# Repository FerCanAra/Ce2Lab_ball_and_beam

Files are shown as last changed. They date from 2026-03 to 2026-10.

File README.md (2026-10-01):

# Unlocking the Development and Experiences ofControl Education Labs (Ce2Lab) 





The shortage of physical lab models in university control engineering laboratories is a widely recognized problem at theinternational level. In response to this challenge, this paper presents CE2Labs (Unlocking the Development and Experiences ofControl Education Labs), a teaching innovation project funded by theIFAC Activity Fundand developed by an internationalteam of educators and laboratory engineers from universities in Spain, Sweden, France, Germany, and the United Kingdom.The project proposes the design and construction of low-cost, open-source physical lab models at different levels of complexity,ranging from 3D-printed mechanical devices to Arduino-based and custom electronics solutions, as well as the developmentof an open-access web platform where educators worldwide can access the materials and share experiences.



Visit the project [OFFICIAL website](https://arm.ual.es/ce2lab2/#) for more information. This work was carried out within the [Automation, Robotics and Mechatronics Group](https://arm.ual.es/arm-group/) (ARM TEP 197) at the University of Almería (Spain).

<a href="https://arm.ual.es/arm-group/"> 
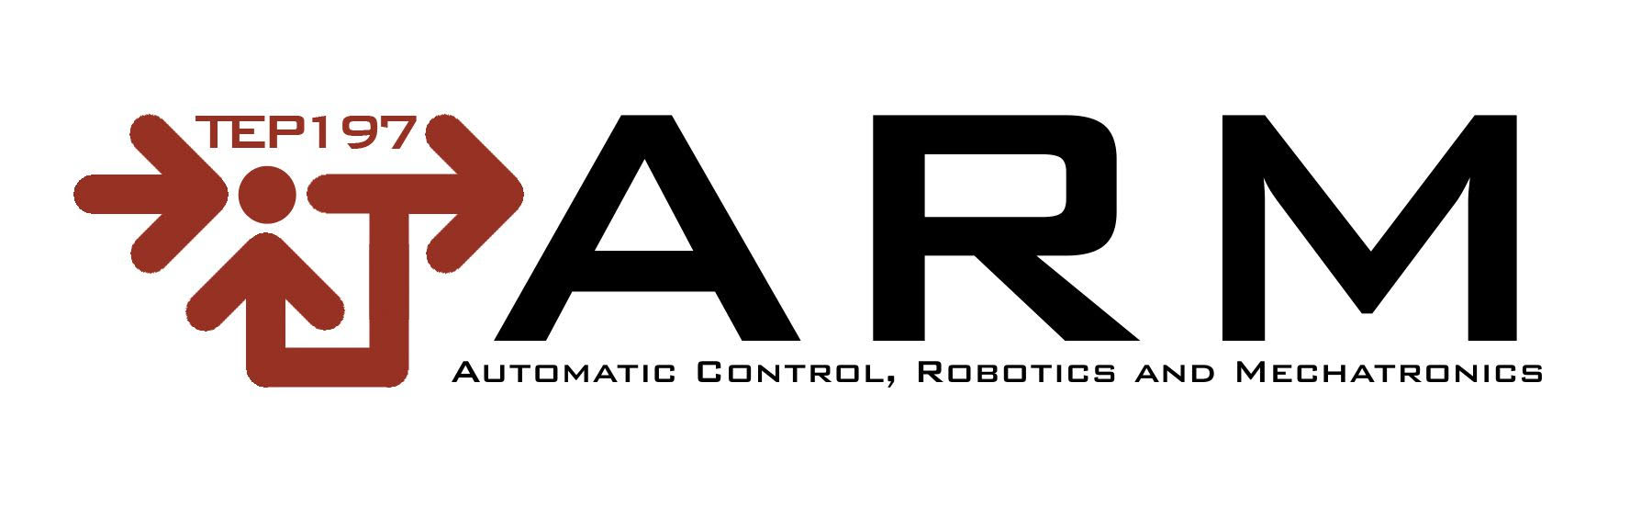
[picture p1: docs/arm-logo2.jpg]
ARM Group Logo
   
</a>
<a href="https://www.linkedin.com/company/automatic-robotics-and-mechatronics-research-group/"> 
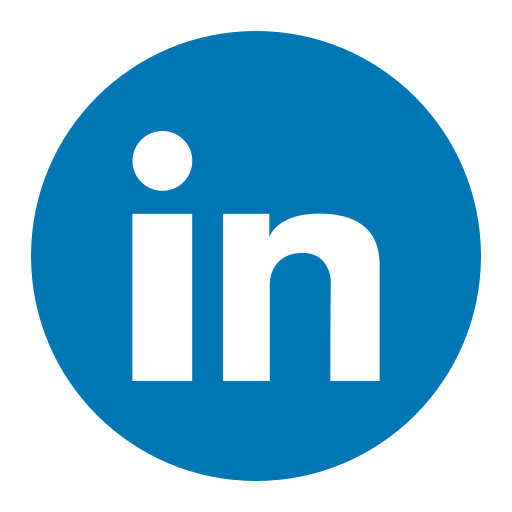
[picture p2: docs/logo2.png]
LinkedIn Logo
   
</a>

## 📑 Citation

**_Project article_**

```
@article{sanchez2026democratizando,
  title={Democratizando los laboratorios de control: la iniciativa CE2Labs},
  author={S{\'a}nchez, Jos{\'e} Luis Guzm{\'a}n and Gil, Juan Diego and Ca{\~n}adas-Ar{\'a}nega, Fernando and Pataro, Igor ML and Rodr{\'\i}guez-Miranda, Enrique and Gonz{\'a}lez-Her{\'a}ndez, Jos{\'e} and Mu{\~n}oz-Rodr{\'\i}guez, Manuel and Berenguel, Manuel},
  journal={Jornadas de Autom{\'a}tica},
  number={47},
  year={2026}
}
```

**_Ball and beam article_**

```
@article{aranega2026plataforma,
  title={Plataforma Ball and Beam de bajo coste como apoyo a la ense{\~n}anza de conceptos introductorios de modelado y control autom{\'a}tico},
  author={Ca{\~n}adas-Aranega,Fernando  and Pataro, Igor M.L. and Rodr{\'\i}guez, Enrique and Gil, Juan Diego and Luis Guzm{\'a}n, Jos{\'e}},
  journal={Jornadas de Autom{\'a}tica},
  number={47},
  year={2026}
}
```
**_Software citation_**
  
```
@software{c2d_project,
  author={Ca{\~n}adas-Aranega,Fernando  and Pataro, Igor M.L. and Rodr{\'\i}guez, Enrique and González, José and Muñoz, Manuel and Gil, Juan Diego and Luis Guzm{\'a}n, Jos{\'e}},
  title   = {Ce2Lab Repository Project},
  version = {0.0.1},
  year    = {2026},
  doi     = {https://doi.org/10.5281/zenodo.23079949},
  url     = {https://github.com/FerCanAra/Ce2Lab_ball_and_beam/tree/main}
}
```

## Ce2Lab - Watt Governor

This repository contains the STL files required to build a simple **Watt Governor demonstrator** for educational use. The objective of the model is to provide a **visual and intuitive demonstration** of how a centrifugal governor works. By rotating the central shaft manually, the user can observe how the rotating masses move outward as the rotational speed increases, causing the central collar to move vertically.

Go to [official site](Watt%20Governor/) for full details on the complete project.

## Ce2Lab - Ball and Beam

The Ball and Beam system is a classic experiment widely used in control engineering to study PID control techniques. The objective of the system is to maintain a ball at a desired position along a beam by adjusting the beam's angle. This is achieved by continuously measuring the ball position and applying a PID control action to a servo motor that tilts the beam.

Go to [official site](Ball%20and%20Beam/) for full details on the complete project.

## License

<details>
<summary>This project is licensed under the **BSD 3-Clause License**.</summary>

Copyright (c) 2026, Fernando Cañadas Aránega, Igor Mendes Lima Pataro, Enrique Rodríguez Miranda, José González Hernández, José Luis Guzmán Sánchez and Juan Diego Gil Vergel.

All rights reserved.

Redistribution and use in source and binary forms, with or without modification,
are permitted provided that the following conditions are met:

1. Redistributions of source code must retain the above copyright notice,
this list of conditions and the following disclaimer.

2. Redistributions in binary form must reproduce the above copyright notice,
this list of conditions and the following disclaimer in the documentation
and/or other materials provided with the distribution.

3. Neither the name of the copyright holders nor the names of its contributors
may be used to endorse or promote products derived from this software without
specific prior written permission.

THIS SOFTWARE IS PROVIDED BY THE COPYRIGHT HOLDERS AND CONTRIBUTORS "AS IS"
AND ANY EXPRESS OR IMPLIED WARRANTIES ARE DISCLAIMED.

For the complete license text see the `LICENSE` file in this repository.
</details>

## Contributor

[Fernando Cañadas Aránega](https://linktr.ee/fercanara), 
Igor Mendes Lima Pataro,
Enrique Rodríguez Miranda, 
José González Hernández,
[Jose Luis Guzman Sánchez](https://w3.ual.es/personal/joguzman/) and
[Juan Diego Gil Vergel](https://w3.ual.es/personal/jdgil/).

## References

Code template: [AntonAshraf](https://github.com/AntonAshraf/Ball-Beam-PID-Control/tree/main)

stl template: [OlegKor25](https://www.thingiverse.com/thing:6387659)

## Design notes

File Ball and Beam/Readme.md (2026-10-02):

# Ce2Lab - Ball and Beam

The Ball and Beam system is a classic experiment widely used in control engineering to study PID control techniques. The objective of the system is to maintain a ball at a desired position along a beam by adjusting the beam's angle. This is achieved by continuously measuring the ball position and applying a PID control action to a servo motor that tilts the beam.

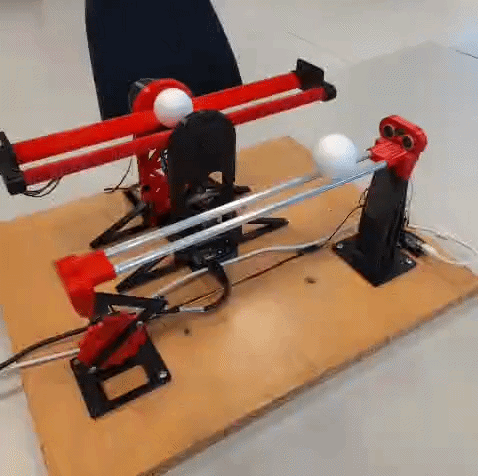
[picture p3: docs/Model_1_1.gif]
 

In this project, a different ATmega328P-based implementation of the Ball and Beam system is developed, using an ultrasonic and laser sensors to measure the ball's position and a servo motor to control the beam angle. A PID (Proportional–Integral–Derivative) controller is implemented to automatically adjust the beam inclination, keeping the ball close to the desired target position.

> **Note:** Process tested with Windows 11 with PlatformIO (VSC) on 8th April 2026.

## Ball and Beam GUI

A web interface is also available, allowing you to run simulations in HTML and connect to the actual model for direct interaction. Follow this [official site](Ball%20and%20Beam%20GUI/) to learn more.

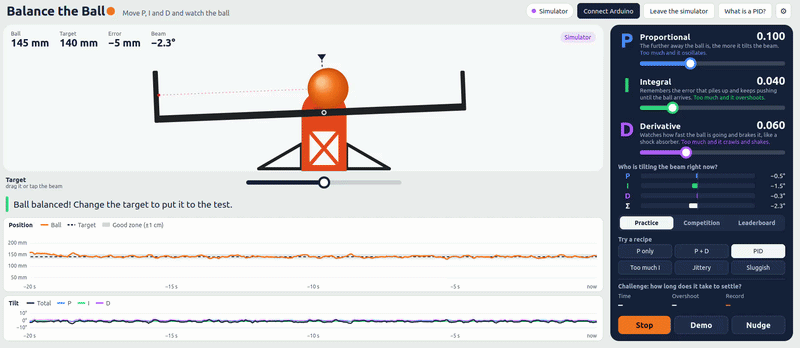
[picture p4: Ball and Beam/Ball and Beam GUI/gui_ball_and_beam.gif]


<details>
<summary>Model 1</summary>

A “Ball and Beam” with its support in the center:

image-removebg-preview


<details>
<summary>1. Materials and cost</summary>

### 3D printing of parts

A Prusa MK4 (0.4 mm nozzle) printer was used. The total printing time is: 7h 39min + 10h 28min + 14h 54min + 1h 34min = 34h 35 min. Parameters:
- Layer height: 0.15 mm
- First layer height: 0.2 mm
- Infill: 5 %
- Raft: No
- Supports: Yes
- Ironing: 15 mm/s

Printing material:

- PLA 1.75 mm
- Extruder temperature: 215 °C
- Bed temperature: 60 °C
- PLA consumption: 78.73 g + 102.63 g + 146.65 g + 13.52 g = 341.53 g (5%)

### Additional material

Mechanical components:
- 12 × M4 Allen screws
- 7 x Jumper Wire 
- 1 x Hot glue
- 1 x Ping-pong ball

Electronic components:
- 1 × ATMega328P (Microcontroller socket board): 10 €
- 1 × MG996r motor: 6 €
- 1 × 341.53 g of PLA roll: 6.50 € (19€/kg)
- 1 × VL53L0X: 1.0 €

### Cost per prototype

Total cost: 23.50 €

</details>

<details>
<summary>2. Assembly</summary>

If you're reusing the code, try connecting everything as shown in the image below:



</details>
</details>
<details>
<summary>Model 2</summary>

A “ball-and-beam” structure supported at one end (with the same model at the other end)




<details>
<summary>1. Materials and cost</summary>

### 3D printing of parts

A Prusa MK4 (0.4 mm nozzle) printer was used. The total printing time is: 12 h 27 min
- Layer height: 0.15 mm
- First layer height: 0.2 mm
- Infill: 5 %
- Raft: No
- Supports: Yes
- Ironing: 15 mm/s

Printing material

- PLA 1.75 mm
- Extruder temperature: 215 °C
- Bed temperature: 60 °C
- PLA consumption: 112.5 g (5%)

### Additional material

Mechanical components:
- 3 × M4 1 cm Allen screws
- 2 x M2 8 cm Allen screws
- 2 x M2 washers
- 1 x 7 mm hollow aluminum rod: 2 €

Electronic components:
- 1 × ATMega328P (Microcontroller SMD board): 3.3 €
- 1 × MG996r motor: 6 €
- 1 × 112.2 g of PLA roll: 2.20 € (19€/kg)
- 1 × HC-SR04: 2.5 €

### Cost per prototype

Total: 16 €

</details>

<details>
<summary>2. Assembly</summary>

If you're reusing the code, try connecting everything as shown in the image below:



</details>
</details>

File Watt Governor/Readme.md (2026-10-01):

## Ce2Lab - Watt Governor

This repository contains the STL files required to build a simple **Watt Governor demonstrator** for educational use.

The purpose of the model is to provide a **visual and intuitive demonstration** of how a centrifugal governor works. By rotating the central shaft manually, the user can observe how the rotating masses move outward as the rotational speed increases, causing the central collar to move vertically.

The model is intended to help explain the balance between centrifugal effects and gravity, as well as the influence of mechanical parameters such as the **mass of the balls** and the **length of the arms**.

<details>
<summary>1. Materials and cost</summary>

### STL files to print

To assemble one complete model, print:

- 2 × `Ball.stl`
- 2 × `Bal_2.stl`
- 1 × `Base.stl`
- 1 × `Slider.stl`
- 1 × `Knob.stl`
- 1 × `Top.stl`
- 1 × `Collar.stl`
- 1 × `Dial.stl`
- 2 × `Arm_couple.stl`
- 2 × `Arm.stl`

## Additional hardware

The following non-printed components are required:

- 6 × M3×20 screws
- 1 x 8 mm aluminium rod
- Hot glue
- 1 × 623Z bearing
- 1 × 608Z bearing
- Hot glue

## Tool
- Hot glue gun
- Steel saw
- Screwdriver

### Cost per prototype

Total cost: 10.50 €

</details>

<details>
<summary>2. Notes</summary>

The demonstrator is designed primarily as a **visual and interpretative teaching aid** rather than as an instrumented control experiment. No motor or rotational-speed sensor is required for the basic activity.

</details>

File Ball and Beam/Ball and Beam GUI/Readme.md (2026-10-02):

# Balance the Ball — getting started

Ball and beam rig with an Arduino UNO, a Hitec HS-422 servo and a VL53L0X ToF sensor.
The PID runs on the Arduino; the PC is only an interface for changing parameters and watching the response.

## Contents

| File | What it is |
|---|---|
| `BallBeam_Expo/BallBeam_Expo.ino` | Arduino firmware: sensor reading, filtering, PID, servo and serial protocol |
| `balance_the_ball.html` | Interface for the public; a single file you open in Chrome or Edge |

If you close the browser the rig keeps controlling, because the loop runs on the Arduino.
That is also why it starts up in PID mode even with no PC attached.

---

## 1. Wiring

| Item | Pin |
|---|---|
| Servo, signal | D11 |
| Servo, power | 5–6 V from a **separate supply** (2 A or more); ground **common** with the Arduino |
| VL53L0X VIN / GND | 5 V / GND (the module has its own regulator) |
| VL53L0X SDA / SCL | A4 / A5 |

During a long public event it matters that the servo is not powered from USB.
When the servo pulls hard, USB can sag below what the UNO needs and the Arduino resets.
The interface counts those resets in the operator panel. If the count climbs, this is why.

## Beam geometry

The beam has been shortened from the original build. The values the program uses are:

| Quantity | Value |
|---|---|
| Ball against the near end stop | 42 mm |
| Ball in the middle of the beam | 140 mm |
| Ball against the far end stop | 238 mm |
| Target, minimum and maximum | 70 and 210 mm |
| Target at start-up | 140 mm |

The 42 mm minimum follows from the other two: if the middle reads 140 and the far stop reads 238, the near stop falls at 140 − (238 − 140) = 42 mm.

If you change the beam length again, only `POS_MIN`, `POS_MAX`, `SP_MIN`, `SP_MAX` and `SP_DEFAULT` at the top of the sketch need editing. The interface reads these from the Arduino as soon as it connects (the `#CFG` message) and adapts the drawing, the target slider and the charts on its own, so the HTML needs no changes.

## 2. Loading the firmware

1. In the Arduino IDE open *Tools → Manage Libraries* and search for **VL53L0X**. Install the one by **Pololu**, not the Adafruit one. The `Servo` library already ships with the IDE.
2. Open `BallBeam_GUI/BallBeam_GUI.ino`. The folder has to have the same name as the file.
3. Select the *Arduino Uno* board and the right port, and upload.
4. If you open the Serial Monitor at 115200 baud you should see `#READY`, `#CFG,...` and lines starting with `$`.
5. **Close the Serial Monitor** before using the interface: only one program at a time can hold the port.

The parameters you may need to touch are grouped at the top of the file: servo pin, position range, default target, angle limits and observer settings.
Everything that depends on your particular build (level angle, direction, limit and gains) is adjusted from the interface and stored in EEPROM.

## 3. Opening the interface

1. Open `balance_the_ball.html` with **Chrome or Edge**. Firefox and Safari do not support Web Serial.
2. Press **Connect Arduino** and pick the port. Next time you open the page it connects on its own.
3. It needs no internet, so you can copy the file to the event laptop and open it directly.

With no rig attached, the **Simulator** button gives you the same controller as the firmware running against your identified model. It is useful for rehearsing the explanation, or for keeping people busy while someone else is using the rig.

## 4. One-off setup (⚙ Operator settings)

1. **Level.** Tick *Manual mode* with the manual tilt at 0°. Adjust *Servo angle that levels the beam* until the ball barely moves. The starting value is 85°.
2. **Sensor.** Move the ball along the beam by hand. The *Sensor reading* should follow it smoothly between about 42 and 238 mm. With the ball in the middle of the beam it should read about 140 mm; if it does not, check the end stops or where the sensor sits.
3. **Direction.** Set a manual tilt of +5°. The ball must move **away from the sensor**. If it comes closer, press *Flip direction*. This build needs −1, which is the default.
4. **Limit.** 15° is a good compromise. Larger values make the rig quicker but also harsher.
5. Untick manual mode and press **Save to the Arduino**. From then on it starts up with these values.

If the ball consistently runs off to one end with the PID recipe, step 3 is wrong. With the direction inverted, the more you raise P the sooner the ball escapes.

---

## 5. How it works inside

### The plant
Tilting the beam accelerates the ball:

`ẍ = K · (θ + tilt error)`, with K ≈ 83.5 mm/s² per degree.

That is the value from the `fmincon` identification: K_b ≈ 4.79 m/s²/rad. The plant is a **double integrator**. Tilt does not set the position of the ball, nor even its speed, but its acceleration.

### Why D is essential
With P alone the beam acts like a spring: it pushes the ball towards the target, but nothing brakes it, so the ball oscillates for ever.
D opposes the speed and plays the part of a damper.
I removes the error that is left when the beam is not perfectly level or friction is in play.

### Units of the gains
- **Kp** [°/mm]: at 0.10, a 10 mm error tilts the beam by 1°.
- **Ki** [°/(mm·s)]: at 0.04, a 10 mm error held for 1 s adds 0.4°.
- **Kd** [°·s/mm]: at 0.06, a ball travelling at 100 mm/s produces 6° of braking.

Starting values: **Kp = 0.10, Ki = 0.04, Kd = 0.06**. These are the ones that already worked on this rig: beam length does not change the relation between tilt and acceleration, so the gains still hold. With the short beam the errors are smaller, the beam tilts less, and the ball settles slightly sooner, in about 3–5 s, with a final error of 5 mm or less.

What does change is the margin to the end stops: from the highest target (210 mm) there are only 28 mm left before the end of the beam. With the more aggressive recipes the ball will touch the stop, bounce, and the controller will recover it. This is harmless and turns out to be rather instructive to watch.

### Filtering: alpha-beta observer with a model
Differentiating a measurement carrying 20–30 mm of noise makes the servo shake.
The firmware first applies a median of 3, which kills the spikes, and then an **observer** that predicts where the ball should be using the model and corrects that prediction with the measurement:
- `α = 0.35` corrects position and `β = 0.05` corrects speed.
- `γ = 0.001` estimates the real tilt error of the beam, bounded to ±5°. Without this term the P+D recipe settled about 20 mm short of the target.
- If the ball jumps more than 60 mm, for instance because someone picks it up, the observer resets.
- Near the end stops it stops using the model and freezes the tilt estimate. Otherwise it "believes" a ball resting against a wall is still moving.

In simulation the servo shake drops from about 1.1–2.6° with conventional filters to about 0.6°.

### PID details
- **Derivative on the measurement**, not on the error, so changing the target produces no sudden kick.
- **Anti-windup**: the integral stops accumulating once the beam is already at its limit in that direction, and it is bounded to ±8° anyway.
- The servo is driven with `writeMicroseconds`, giving about 0.1° of resolution instead of 1°.
- The sensor is polled without blocking. If it fails, the beam goes level and the Arduino retries once a second.

---

## 6. The interface for the public

- **P, I and D sliders**, each with a plain-language line and a warning about what happens if you overdo it.
- **"Who is tilting the beam right now?"**: shows in real time how many degrees each term contributes. This is the single most useful panel for explaining a PID.
- **Recipes**, worth trying in this order:
  - **P only**: the ball oscillates.
  - **P + D**: it settles, but about 18 mm short of the target.
  - **PID**: it reaches the target.
  - **Too much I**: it overshoots.
  - **Jittery**: it shakes.
  - **Sluggish**: it never gets there.
- **Coach**: suggests which slider to move based on what the ball is doing.
- **Challenge** (*Practice* tab): move the target by 3 cm or more and it times how long the ball takes to stay within ±1 cm for 1.5 s, and keeps the record. If someone touches the gains halfway through, that time does not count.
- **Target**: set by dragging on the drawing of the beam or with the slider below it.
- **Keyboard**: *Space* stops or starts, *Esc* closes panels. During a competition, *Space* stops control and voids the go.
- **Automatic demo** after 90 s with nobody touching anything: it goes back to the PID recipe and cycles through targets. It can be turned off in ⚙.

### Competition mode

On the **Competition** tab, the *Start* button deals out a random target and random gains, starts the clock and waits. You have to move P, I and D until the ball sits still on the target (±1 cm) for **3 seconds in a row**. The time runs from *Start* to the moment the ball entered the good zone and never left it again.

On success a dialog shows the time, the position obtained and a box for a name. The **Leaderboard** tab shows the standings.

Details worth knowing for the event:

- The starting gains come from four archetypes (no brakes, extremely jittery, too much memory, everything maxed out), with random values inside each. They are chosen so that **none of them settles on its own**: this was checked over 320 simulated goes, with the beam level and with a tilt error of ±1.5°. Nobody wins without touching anything.
- The target always lands 7 cm or more from wherever the ball is, so there is ground to cover.
- During a go the target slider, the recipes and the demo button are locked. Otherwise pressing "PID" would be enough to win.
- The coach stops giving hints during a go and only reports the time. If you would rather it kept helping, for instance with small children, turn it on in ⚙ → *Keep the coach hints during the competition*.
- If someone stops control, switches to manual mode, or the Arduino resets, the go is voided. The limit per go is 2 minutes.
- The leaderboard is stored in the browser on the laptop (`localStorage`), so it survives reloading the page and closing the browser. Clear it from ⚙ → *Clear the leaderboard*. It is a good idea to empty it right before opening to the public.
- If the browser has local storage blocked, the interface says so on the leaderboard tab and the standings last only while the page is open.

### Tips for the event
- Walk people through this sequence: *P only → raise the D → raise the I*. That is how each letter earns its place. Once someone has the three letters, move them to the competition tab: that is where it hooks.
- Leave the good values saved on the Arduino so a reset does not leave the rig out of tune.
- Go full screen (F11) and stop the laptop from sleeping.
- Bring a spare ball. Ping-pong balls get dented, and a dented ball rolls differently.

---

## 7. Serial protocol (115200 baud, one command per line)

Useful if you want to drive the firmware from MATLAB or Python.

**PC → Arduino**

| Command | Meaning |
|---|---|
| `P0.1` `I0.04` `D0.06` | Gains |
| `S180` | Target in mm (between 70 and 210) |
| `M0` / `M1` / `M2` | Stopped (beam level) / PID / manual |
| `A5` | Angle in manual mode (°) |
| `L15` | Tilt limit (°) |
| `N85` | Servo angle that levels the beam |
| `X-1` | Servo direction |
| `R` | Clear the integral |
| `W` | Store in EEPROM |
| `?` | Resend the configuration |

**Arduino → PC**

- `$t,pos,sp,u,p,i,d,mode,raw,ok,tilt` at about 30 Hz.
- `#CFG,...` with the current configuration.
- `#SAVED` once stored in EEPROM.
- `#ERR,SENSOR` if the sensor fails.
- `#READY` on start-up.

## 8. Common problems

| Symptom | Likely cause |
|---|---|
| "Port busy" | The IDE Serial Monitor is open |
| The reset counter climbs | The servo is powered from USB |
| The ball always escapes to one end | Direction inverted (step 3) |
| With P at zero the ball rolls on its own | Level angle not adjusted (step 1) |
| The reading jumps a lot | Dirty sensor, direct sunlight, or the ball outside its measuring range |
| No connect button appears | The browser is not Chrome or Edge |

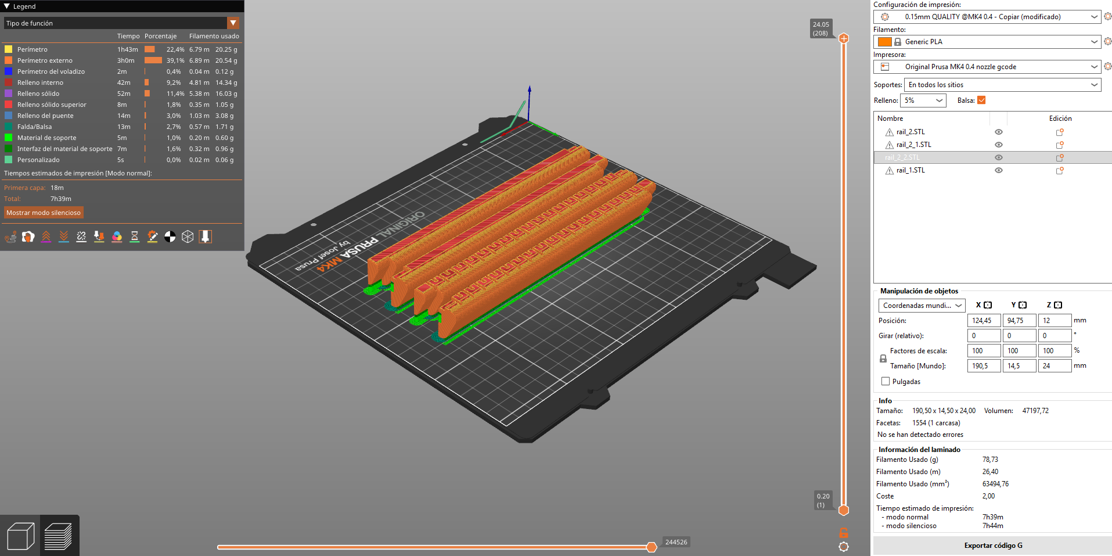
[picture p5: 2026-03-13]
Ball and Beam/Model 1/images/info_1.png

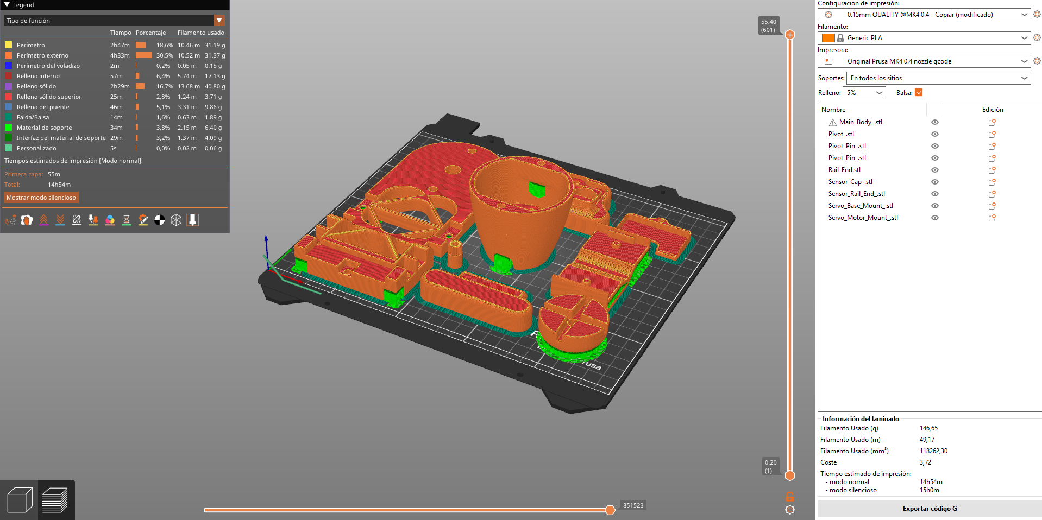
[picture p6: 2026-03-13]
Ball and Beam/Model 1/images/info_4.png

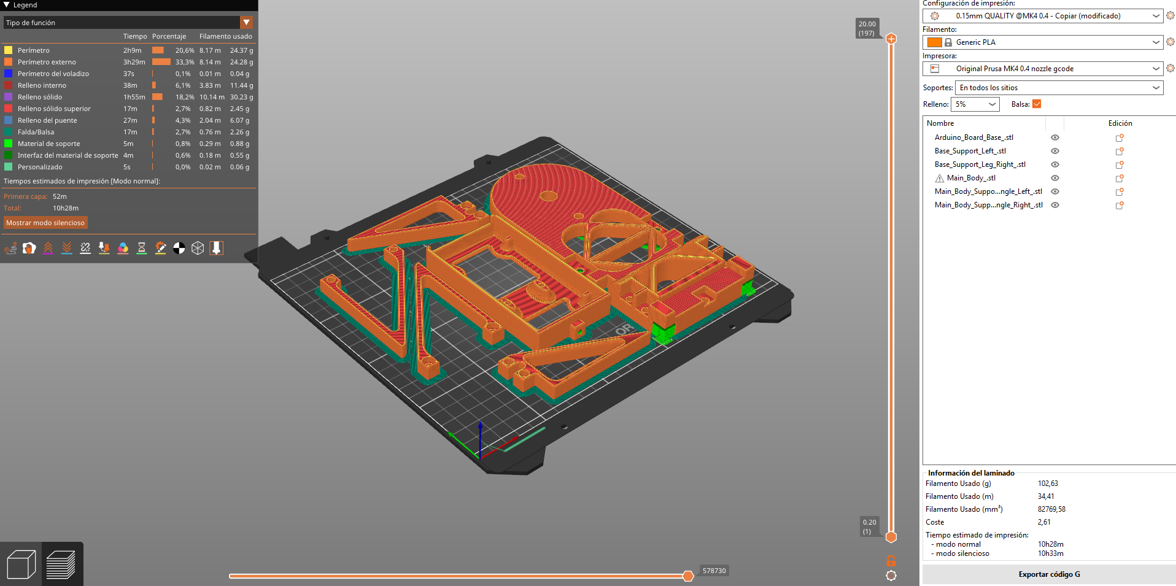
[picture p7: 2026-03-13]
Ball and Beam/Model 1/images/info_2.png

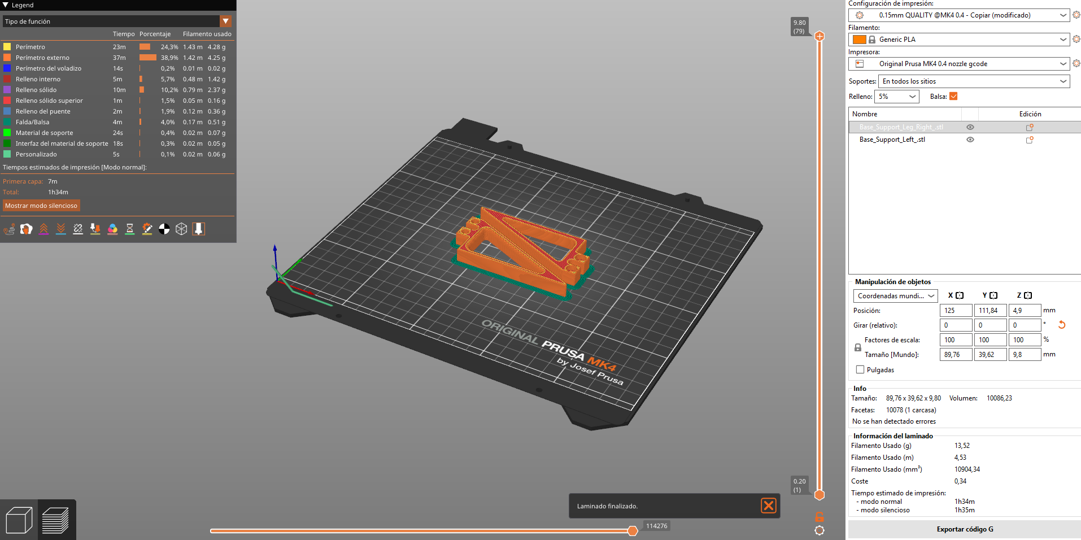
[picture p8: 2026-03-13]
Ball and Beam/Model 1/images/info_5.png

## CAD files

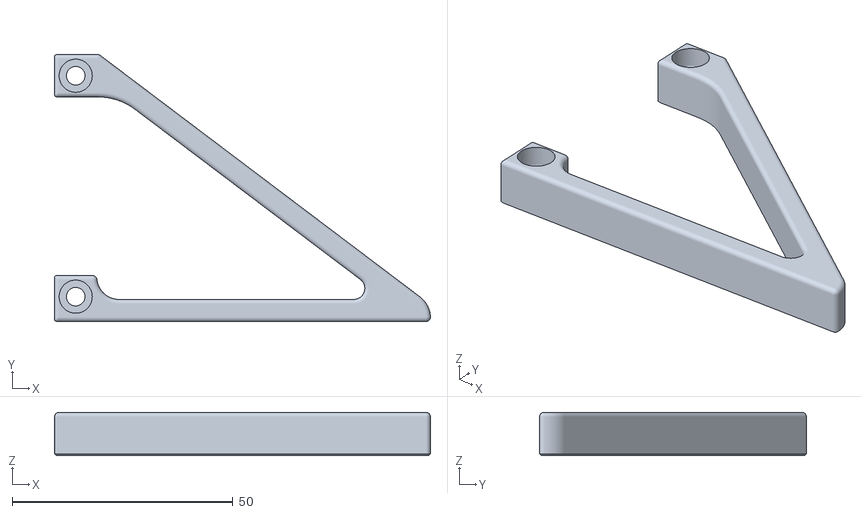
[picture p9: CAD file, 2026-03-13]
Ball and Beam/Model 1/stl/Main_Body_Support_Triangle_Left_.stl
85.1 x 60.4 x 9.80

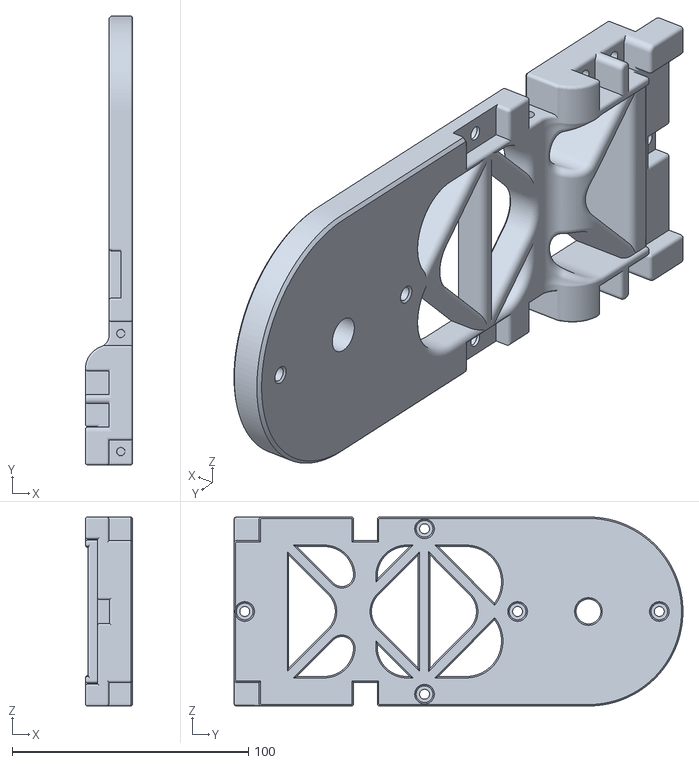
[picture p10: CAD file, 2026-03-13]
Ball and Beam/Model 1/stl/Main_Body_.stl
20.0 x 190.0 x 80.0

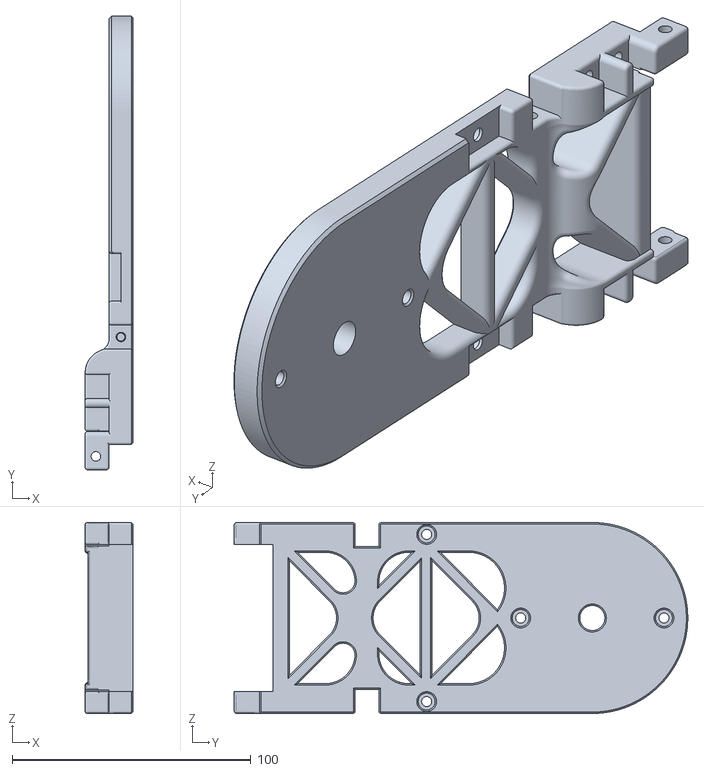
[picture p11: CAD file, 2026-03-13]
Ball and Beam/Model 1/stl/Main_Body_2.STL
20.0 x 190.0 x 80.0

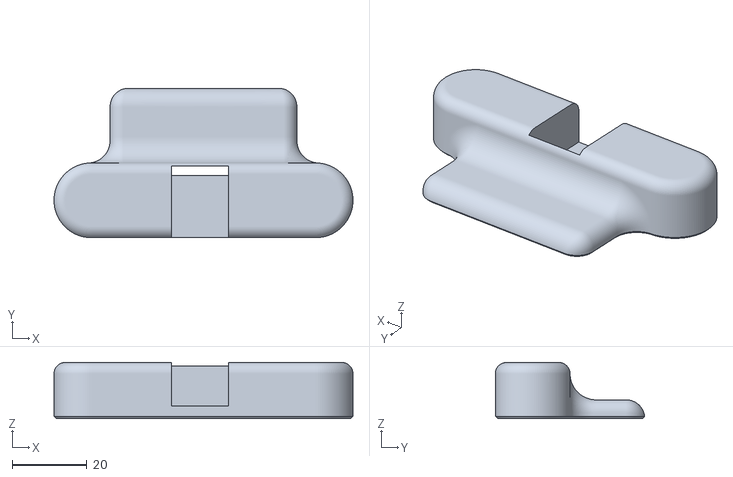
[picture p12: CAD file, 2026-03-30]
Ball and Beam/Model 1/stl/Rail_End_sensor.STL
80.0 x 40.0 x 15.0

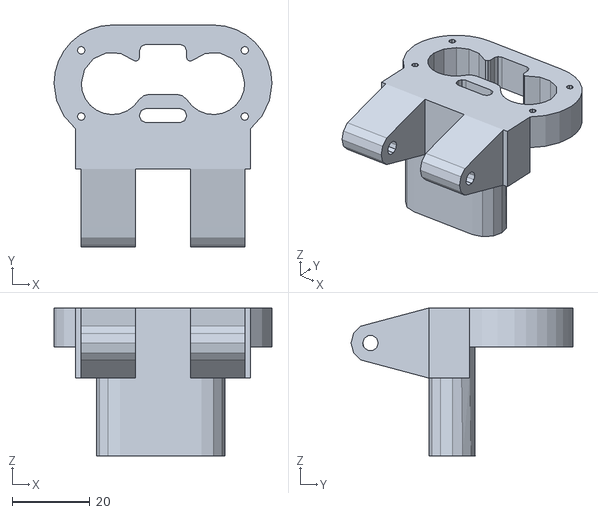
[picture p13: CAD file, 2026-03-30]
Ball and Beam/Model 2/stl/Ultrasonic_sensor_.stl
56.0 x 57.0 x 38.0

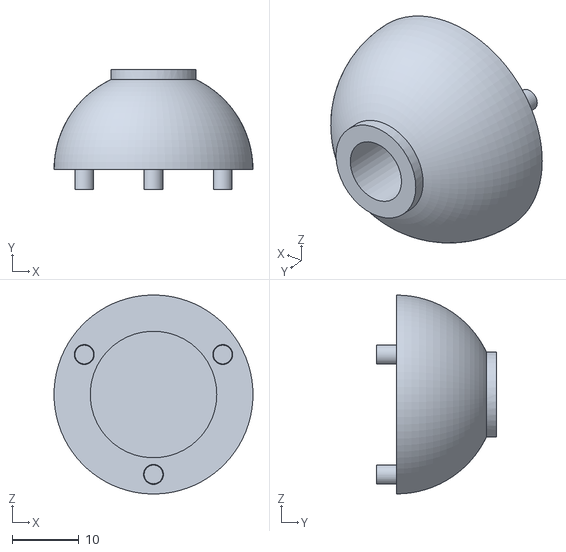
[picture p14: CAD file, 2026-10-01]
Watt Governor/stl/Ball_2.STL
29.9 x 18.0 x 29.8

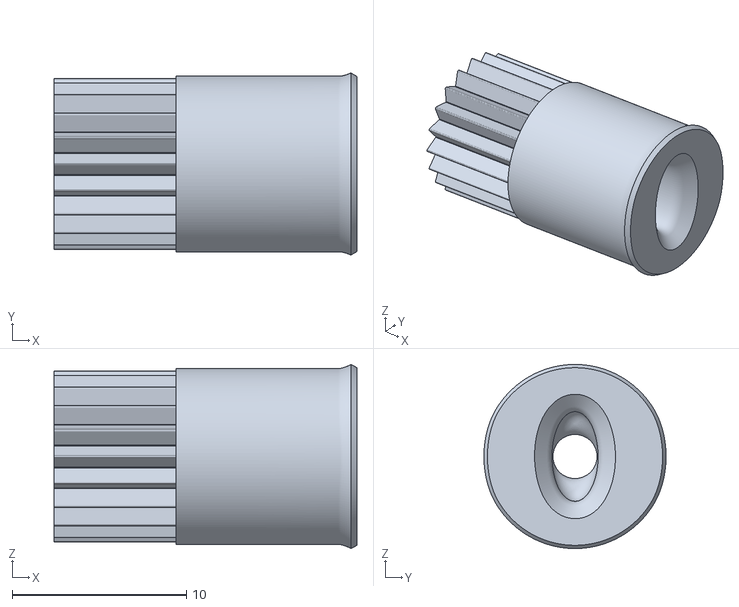
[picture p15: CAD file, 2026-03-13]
Ball and Beam/Model 1/stl/Pivot_Pin_.stl
17.4 x 10.5 x 10.6

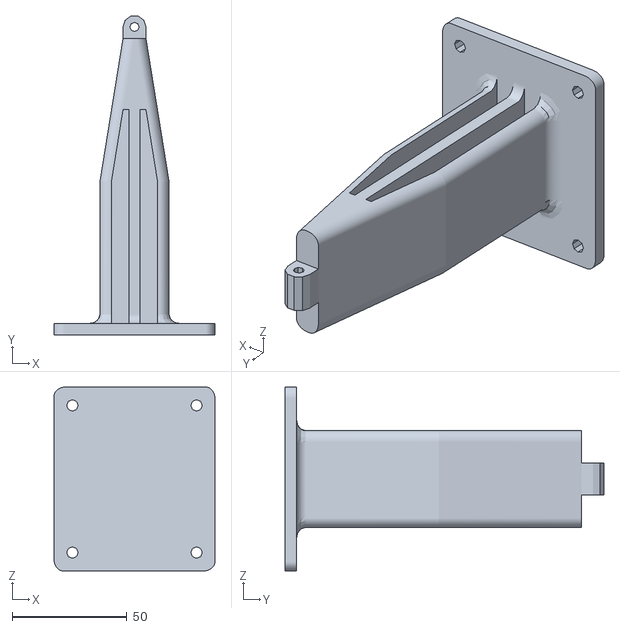
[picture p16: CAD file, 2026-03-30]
Ball and Beam/Model 2/stl/base.stl
70.0 x 138.8 x 80.0

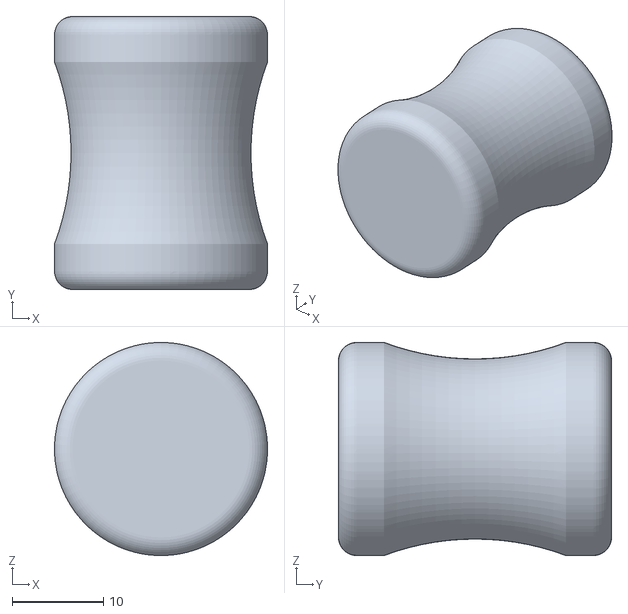
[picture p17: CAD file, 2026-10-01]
Watt Governor/stl/Knob.STL
23.4 x 30.0 x 23.4

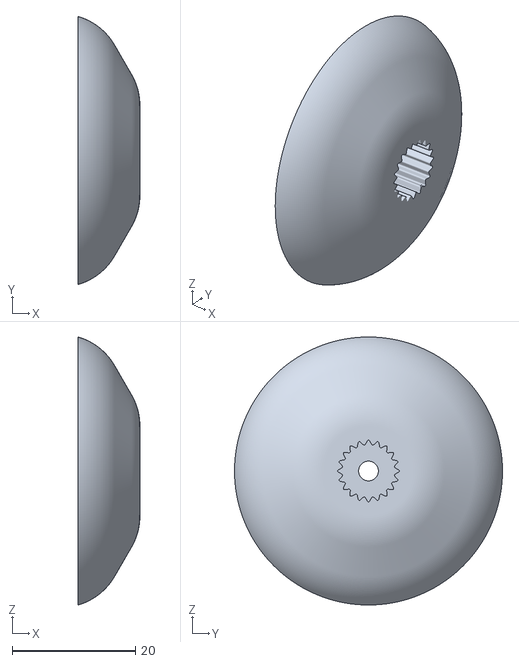
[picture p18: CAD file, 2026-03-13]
Ball and Beam/Model 1/stl/Servo_Motor_Mount_2.STL
10.0 x 43.5 x 43.5

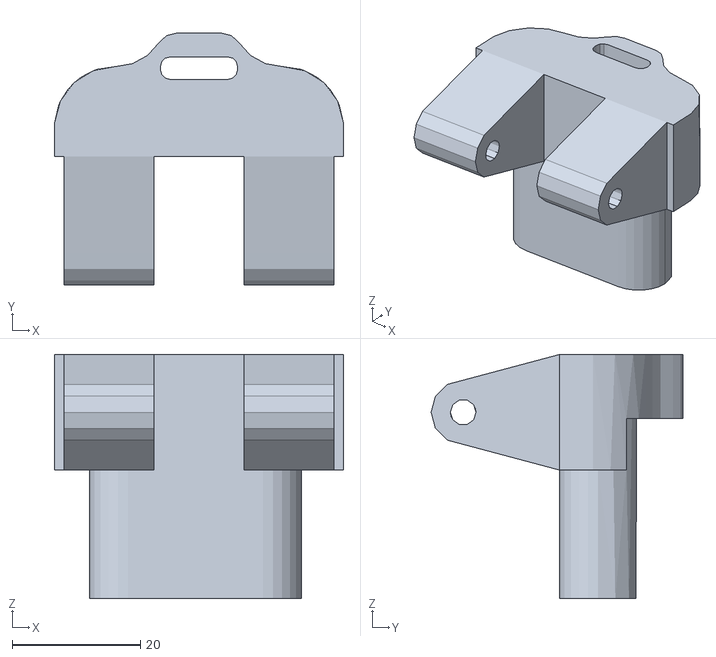
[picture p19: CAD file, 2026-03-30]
Ball and Beam/Model 2/stl/rail_end_.stl
45.0 x 39.2 x 38.0

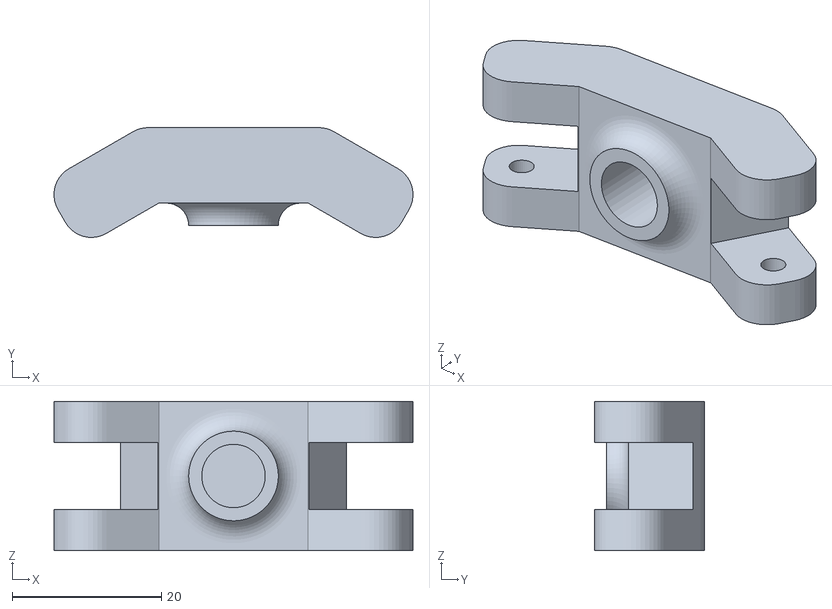
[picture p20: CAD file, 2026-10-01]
Watt Governor/stl/Top.STL
48.0 x 14.7 x 20.0

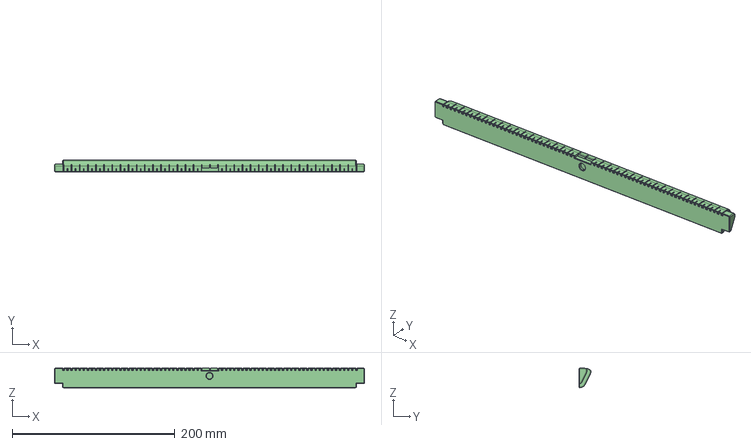
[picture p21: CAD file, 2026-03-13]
Ball and Beam/Model 1/stl/Rail_wRuler_.step
381.0 x 14.5 x 24.0 mm

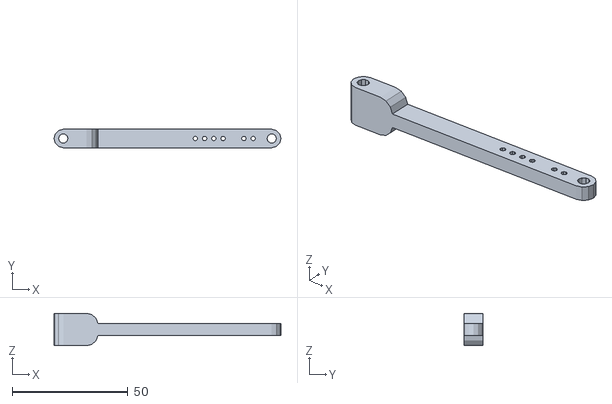
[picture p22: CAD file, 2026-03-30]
Ball and Beam/Model 2/stl/biel.stl
98.0 x 8.00 x 14.0

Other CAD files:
Ball and Beam/Model 1/stl/Main_Body_Support_Triangle_Right_.stl
Watt Governor/stl/Arm_63mm.STL
Ball and Beam/Model 2/stl/Servobase.stl
Watt Governor/stl/Base.STL
Ball and Beam/Model 1/stl/Arduino_Board_Base_.stl
Ball and Beam/Model 1/stl/Base_Support_Left_.stl
Ball and Beam/Model 1/stl/Base_Support_Leg_Right_.stl
Ball and Beam/Model 1/stl/Breadboard_Bracket_Print_x2.stl
Ball and Beam/Model 1/stl/Pivot.STL
Ball and Beam/Model 1/stl/Pivot_.stl
Ball and Beam/Model 1/stl/Pivot_Pin_2.STL
Ball and Beam/Model 1/stl/Rail_.step
Ball and Beam/Model 1/stl/Rail_.stl
Ball and Beam/Model 1/stl/Rail_End.stl
Ball and Beam/Model 1/stl/Rail_with_Ruler.stl
Ball and Beam/Model 1/stl/Servo_Base_Mount_.STL
Ball and Beam/Model 1/stl/Servo_Motor_Mount_.stl
Watt Governor/stl/Arm.STL
Watt Governor/stl/Arm_53mm_.STL
Watt Governor/stl/Arm_couple.STL
Watt Governor/stl/Ball.STL
Watt Governor/stl/Collar.STL
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

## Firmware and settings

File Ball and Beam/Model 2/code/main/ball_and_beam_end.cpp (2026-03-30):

/* -------------------------------------------------------------------------------------------------------------
Project: Ball and Beam PID Control System

Authors:
Fernando Cañadas Aránega, email: fernando.ca@ual.es
Enrique Rodriguez Miranda, email: erm969@ual.es
José Luis Guzmán Sánchez, email: joguzman@ual.es

License: BSD 3-Clause License
Copyright (c) 2026, Fernando Cañadas Aránega, Enrique Rodriguez Miranda and José Luis Guzmán Sánchez.
All rights reserved.

See the LICENSE file or the README.md for full license information.
// NOTE: For the beam to be horizontal,
// the servo motor angle should be about 95 degrees.
-------------------------------------------------------------------------------------------------------------
*/ 
#include <Arduino.h>
#include <Servo.h>
#include <PID_v1.h>

// Function prototypes (we will define them later)
void resetServo();      // Moves the servo to a safe starting position
float readPosition();   // Reads the distance from the ultrasonic sensor

// Pins used by the ultrasonic sensor
const int trigPin = 9;
const int echoPin = 10;

// Pin used by the servo motor
const int servoPin = 11;

// PID parameters
// These numbers define how strongly the system corrects errors
float Sp = 10;   // Setpoint (desired distance in cm)
float Kp = 0.25;   // Proportional correction (reacts to the error)
float Ki = 0.0;    // Integral correction (reacts to accumulated error)
float Kd = 0.2;    // Derivative correction (smooths the movement)

// Variables used by the PID controller
double Setpoint, Input, Output, ServoOutput;

// Create the PID controller object
PID myPID(&Input, &Output, &Setpoint, Kp, Ki, Kd, DIRECT);

// Create the servo object
Servo myServo;

// Filter parameters
// This filter helps smooth the distance measurement
float alpha = 0.4;              // Number between 0 and 1
float filteredDistance = 0.0;   // Memory of the filtered value

void setup() {

  // Start communication with the computer
  Serial.begin(9600);

  // Attach the servo motor to its pin
  myServo.attach(servoPin);

  // Move the servo to a safe starting position
  resetServo();

  // Configure ultrasonic sensor pins
  pinMode(trigPin, OUTPUT);
  pinMode(echoPin, INPUT);  

  // Take the first distance measurement to initialize the filter
  filteredDistance = readPosition();
  Input = filteredDistance;

  // Turn on the PID controller
  myPID.SetMode(AUTOMATIC);

  // Limit how much the servo can move
  myPID.SetOutputLimits(-60,80);
}

void loop(){

  // Wait 50 milliseconds
  // This means the system updates 20 times per second
  delay(50);

  // Desired distance (target)
  // The system will try to keep the ball at 8 cm
  Setpoint = Sp;

  // Read the real distance from the sensor
  float rawDistance = readPosition();

  // LOW-PASS FILTER
  // This makes the measurement smoother and less noisy
  filteredDistance = alpha * rawDistance + (1 - alpha) * filteredDistance;

  // The filtered value is used as the system input
  Input = filteredDistance;

  // The PID controller calculates how much to move the servo
  myPID.Compute();
  
  // Convert PID output into a servo angle
  ServoOutput = 95 + Output;

  // Move the servo to that angle
  myServo.write(ServoOutput);

  // Print information to the serial monitor
  Serial.print("Raw: ");          // Raw sensor distance
  Serial.print(rawDistance);

  Serial.print("  Filtered: ");   // Filtered distance
  Serial.print(filteredDistance);

  Serial.print("  Angle: ");      // Servo angle
  Serial.println(ServoOutput);
}

// This function centers the servo
void resetServo() {
  myServo.write(90);   // 90 degrees is the middle position
  delay(500);          // Wait half a second
}

// This function measures distance using the ultrasonic sensor
float readPosition() {

  // Send a short pulse so the sensor emits a sound wave
  digitalWrite(trigPin, LOW);
  delayMicroseconds(2);

  digitalWrite(trigPin, HIGH);
  delayMicroseconds(10);
  digitalWrite(trigPin, LOW);

  // Wait until the echo returns
  long duration = pulseIn(echoPin, HIGH);

  // Convert echo time into distance (in cm)
  float distance = duration * 0.034 / 2;

  // If the value is strange or too large,
  // we use a fixed value to avoid errors
  if (distance > 30 || distance <= 0) {
    distance = 40;
  }

  return distance;
}

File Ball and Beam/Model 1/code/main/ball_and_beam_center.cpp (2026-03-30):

/* -------------------------------------------------------------------------------------------------------------
Project: Ball and Beam PID Control System

Authors:
Fernando Cañadas Aránega, email: fernando.ca@ual.es
Enrique Rodriguez Miranda, email: erm969@ual.es
José Luis Guzmán Sánchez, email: joguzman@ual.es

License: BSD 3-Clause License
Copyright (c) 2026, Fernando Cañadas Aránega, Enrique Rodriguez Miranda and José Luis Guzmán Sánchez.
All rights reserved.

See the LICENSE file or the README.md for full license information.
// NOTE: For the beam to be horizontal,
// the servo motor angle should be about 95 degrees.
-------------------------------------------------------------------------------------------------------------
*/ 
#include <Arduino.h>
#include <Servo.h>
#include <PID_v1.h>
#include <Wire.h>
#include <VL53L0X.h>

// Function prototypes
void resetServo();
float readPosition();

// Pin del servo
const int servoPin = 11;

// PID parameters
float St = 22; // Setpoint (cm)
float Kp = 0.75;
float Ki = 0.0;
float Kd = 0.5;

// Variables PID
double Setpoint, Input, Output;

// PID object
PID myPID(&Input, &Output, &Setpoint, Kp, Ki, Kd, DIRECT);

// Objetos
Servo myServo;
VL53L0X sensor;

// Filtro
float alpha = 0.4;
float filteredDistance = 0.0;

void setup() {
  Serial.begin(9600);
  delay(2000);

  Serial.println("Inicializando sistema...");

  // I2C
  Wire.begin();
  if (!sensor.init()) {
    Serial.println("ERROR: No se detecta VL53L0X");
    while (1);
  }

  sensor.setTimeout(500);
  sensor.setMeasurementTimingBudget(50000);

  Serial.println("Sensor OK");

  // Servo
  myServo.attach(servoPin);
  resetServo();

  // Inicializar filtro
  filteredDistance = readPosition();
  Input = filteredDistance;

  // PID
  myPID.SetMode(AUTOMATIC);
  myPID.SetOutputLimits(-60, 80);

  Serial.println("Sistema listo");
}

void loop() {
  delay(50);

  Setpoint = St;

  float rawDistance = readPosition();

  // Low-pass filter for sensor noise
  filteredDistance = alpha * rawDistance + (1 - alpha) * filteredDistance;

  Input = filteredDistance;

  myPID.Compute();

  double servoAngle = 95 + Output; // 95° so that the mount is horizontal (adjust it using test_servo.ino for your model)

  // Physical limits of the motor
  servoAngle = constrain(servoAngle, 0, 180);

  myServo.write(servoAngle);

  Serial.print("Raw: ");
  Serial.print(rawDistance);
  Serial.print("  Filtered: ");
  Serial.print(filteredDistance);
  Serial.print("  Output: ");
  Serial.print(Output);
  Serial.print("  Angle: ");
  Serial.println(servoAngle);
}

// Reset servo
void resetServo() {
  myServo.write(95); 
  delay(500);
}

// Lectura sensor
float readPosition() {
  uint16_t distance = sensor.readRangeSingleMillimeters();
  float distanceCm = distance / 10.0;

  if (sensor.timeoutOccurred()) {
    Serial.println("Timeout sensor");
    return 30;
  }

  // Saturación
  if (distanceCm > 30 || distanceCm <= 0) {
    distanceCm = 30;
  }
  return distanceCm;
}

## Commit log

2026-03-13 Revise README with printing and material information
    Updated the README with new printing parameters and material details.
2026-03-13 Update README.md by modifying images and parameters
    Removed an image and added a second image with printing parameters.
2026-03-26 Update material costs and add VL53L0X sensor
2026-03-30 Update printing times and material costs in README
2026-03-30 Revise printing time and material costs in README
    Updated printing time and PLA consumption details in the README.
2026-03-30 Clarify control techniques in README
    Updated the description to specify PID control techniques.
2026-04-08 Revise additional materials and total costs in README
    Updated material list and costs for prototypes.
2026-04-08 Revise README with image size adjustments and links
    Updated image sizes and added ARM Group links.
2026-04-08 Replace assembly image in README
    Updated image link in assembly section of README.
2026-10-01 Enhance Readme with project details and assembly info
    Added detailed project description, materials, costs, and assembly instructions for the Ball and Beam system.
